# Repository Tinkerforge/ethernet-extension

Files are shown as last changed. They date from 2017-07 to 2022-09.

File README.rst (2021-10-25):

Ethernet Extension
==================

This repository contains the hardware design files.
The software is included in the Master Brick software
and can be found at https://github.com/Tinkerforge/master-brick

Repository Content
------------------

hardware/:
 * Contains KiCad project files and additionally schematics as PDF

datasheets/:
 * Contains datasheets for sensors and complex ICs that are used

Hardware
--------

The hardware is designed with the open source EDA Suite KiCad
(http://www.kicad.org). Before you are able to open the files,
you have to install the Tinkerforge kicad-libraries
(https://github.com/Tinkerforge/kicad-libraries). You can either clone
them directly in hardware/ or clone them in a separate folder and
symlink them into hardware/
(ln -s kicad_path/kicad-libraries project_path/hardware). After that you
can open the .pro file in hardware/ with KiCad and from there view and
modify the schematics and the PCB layout.

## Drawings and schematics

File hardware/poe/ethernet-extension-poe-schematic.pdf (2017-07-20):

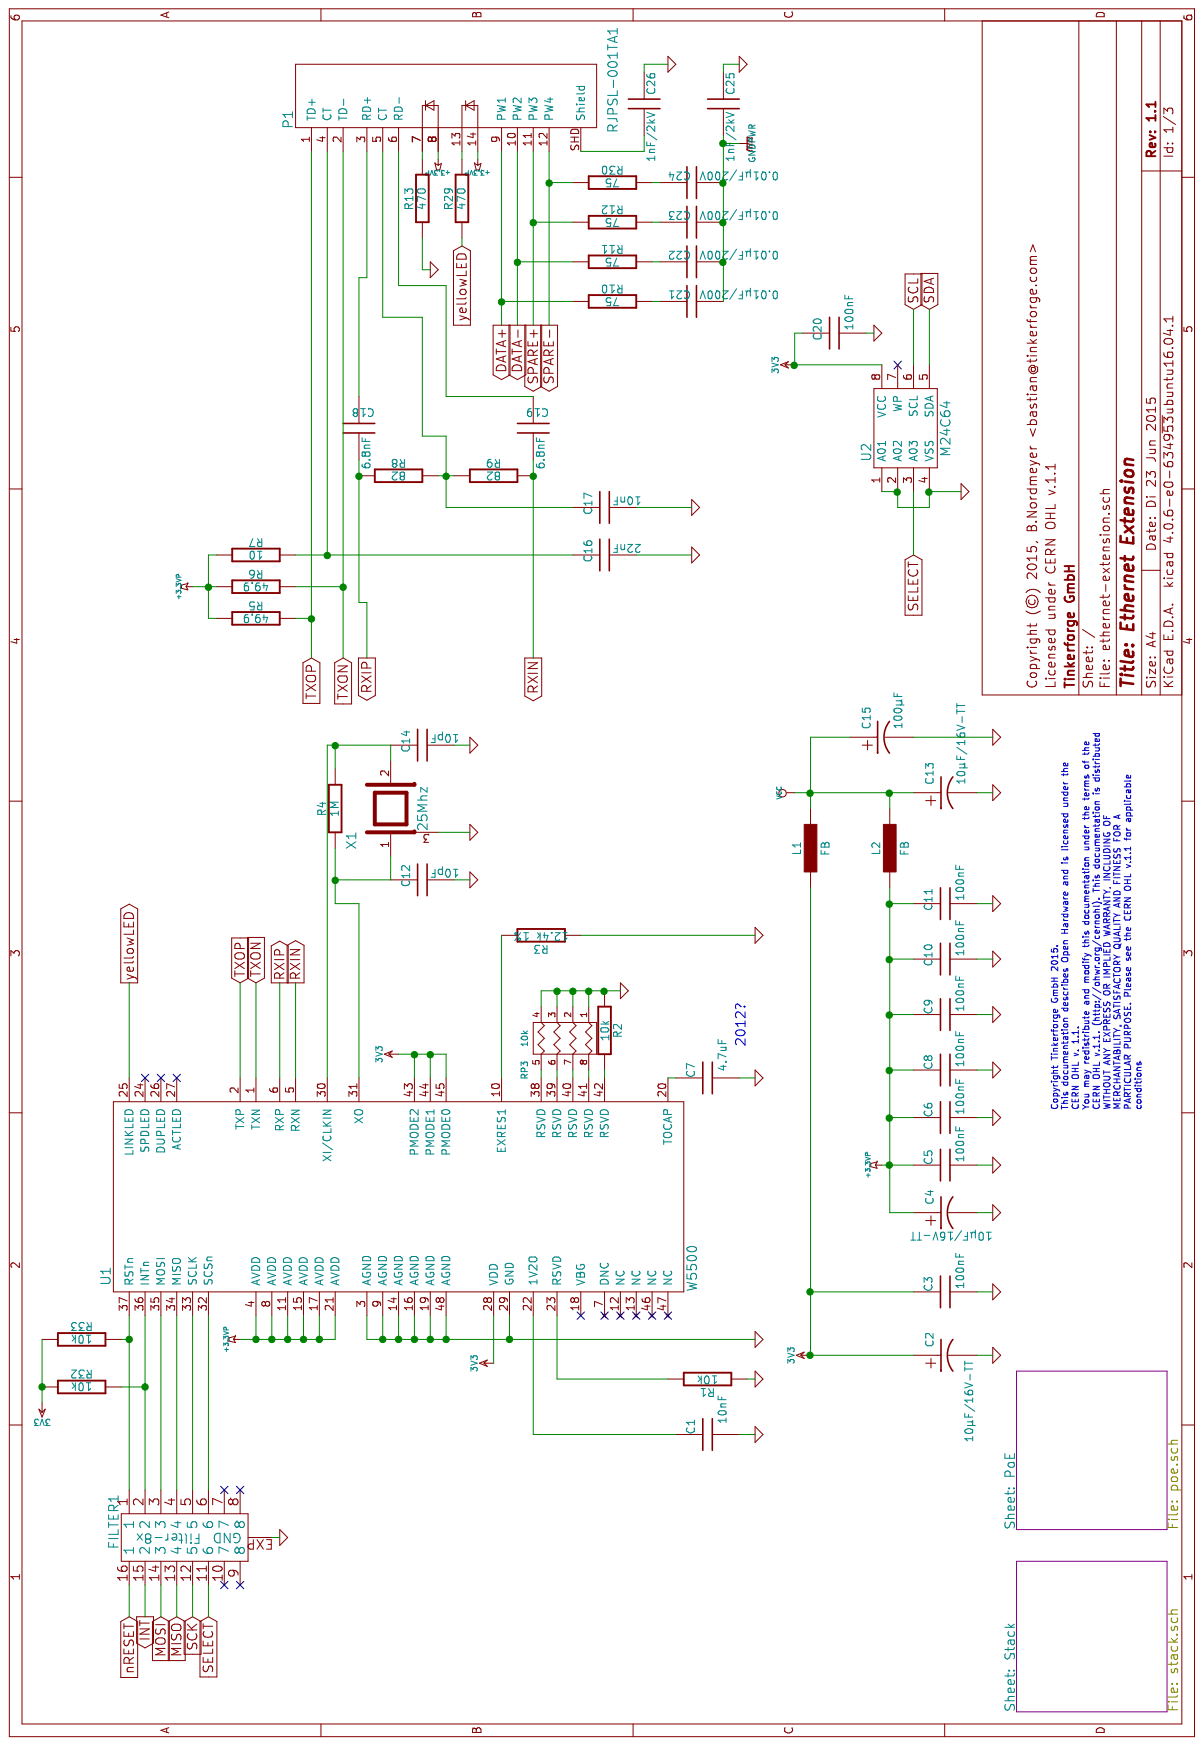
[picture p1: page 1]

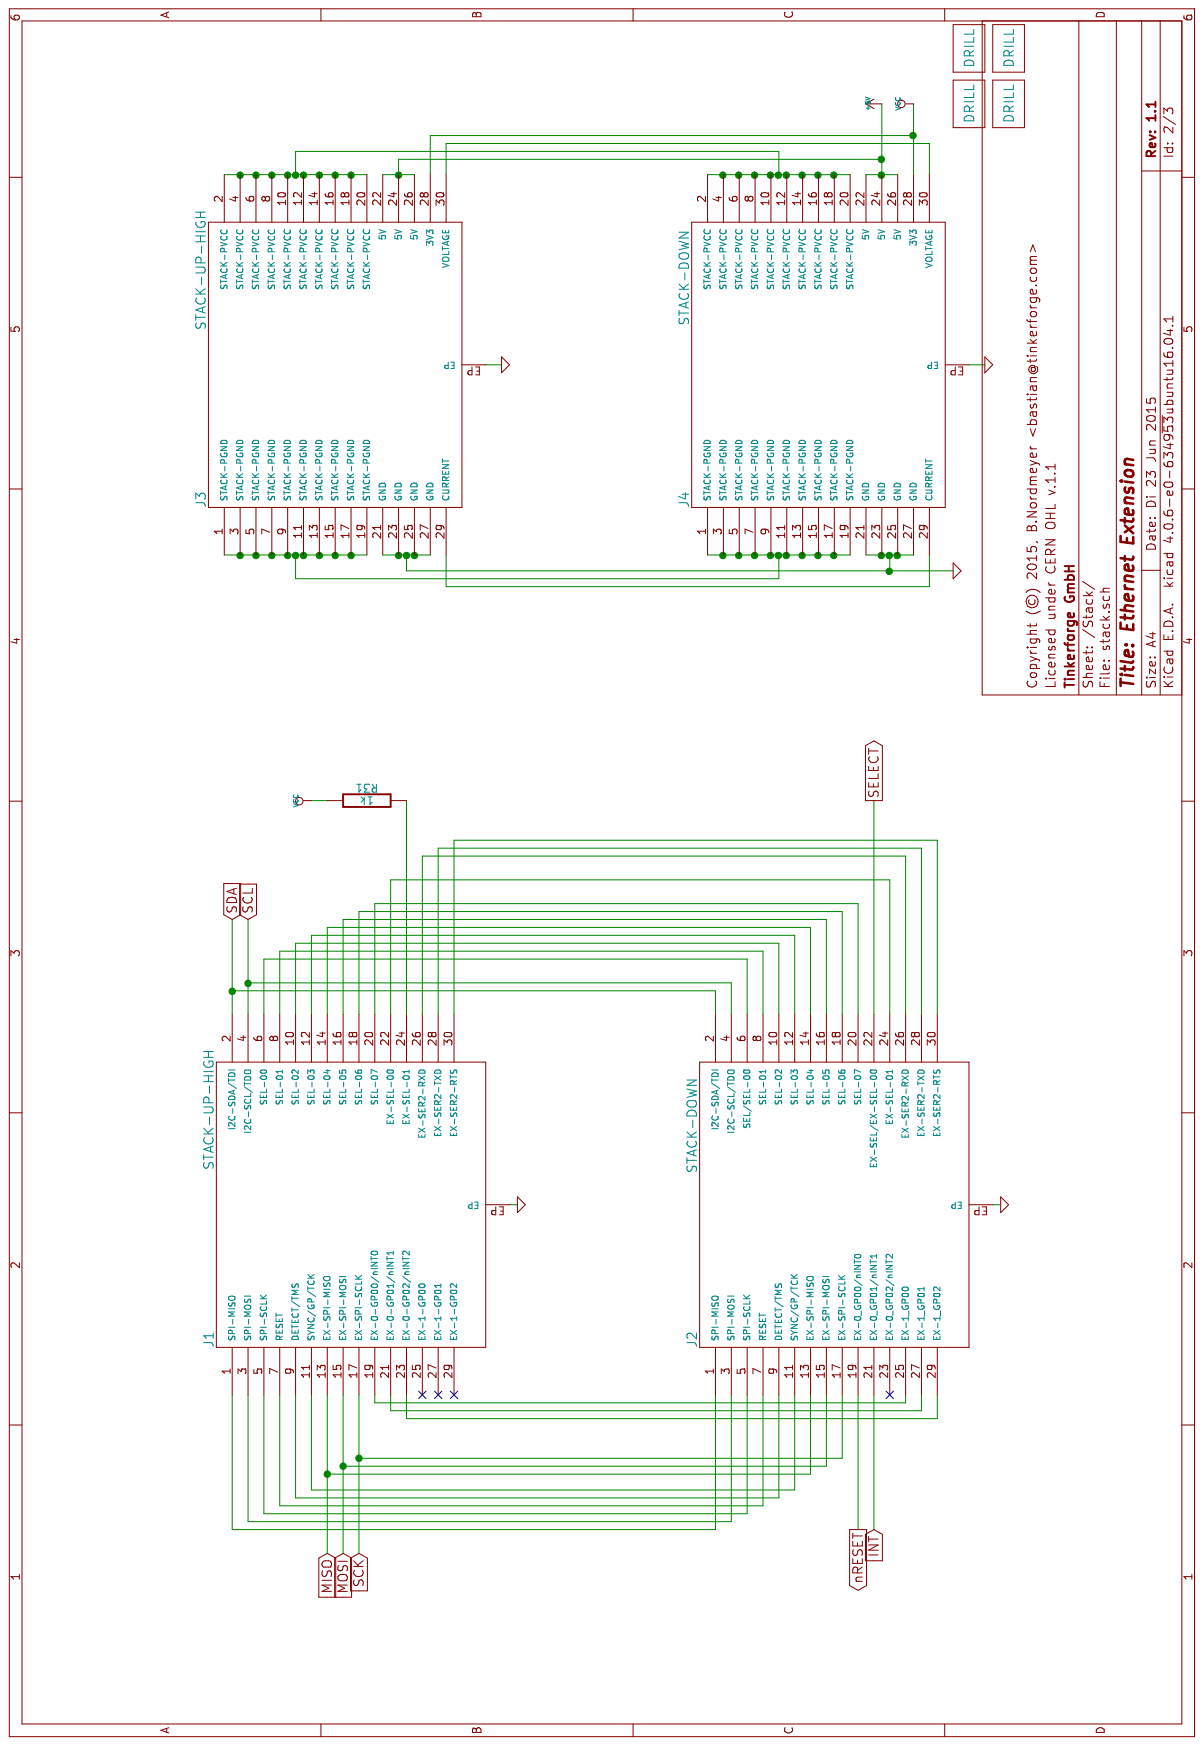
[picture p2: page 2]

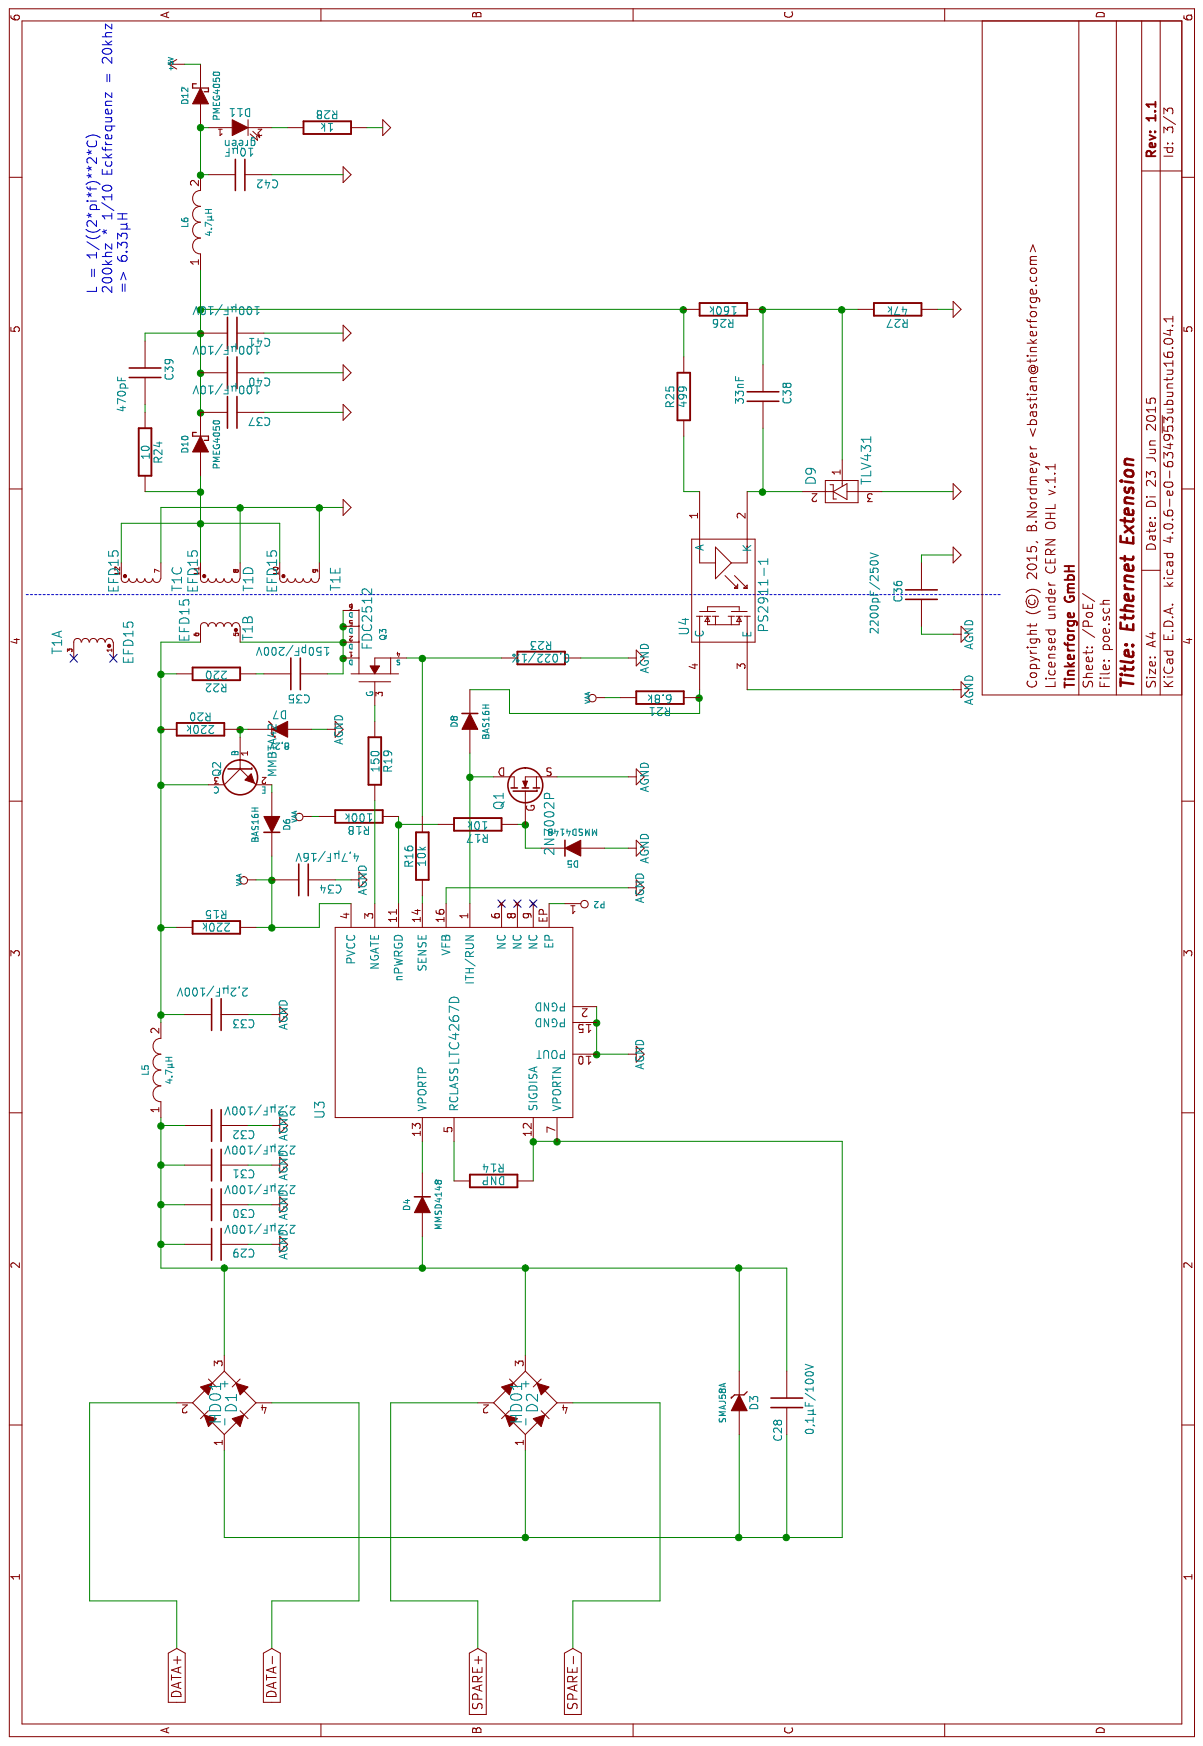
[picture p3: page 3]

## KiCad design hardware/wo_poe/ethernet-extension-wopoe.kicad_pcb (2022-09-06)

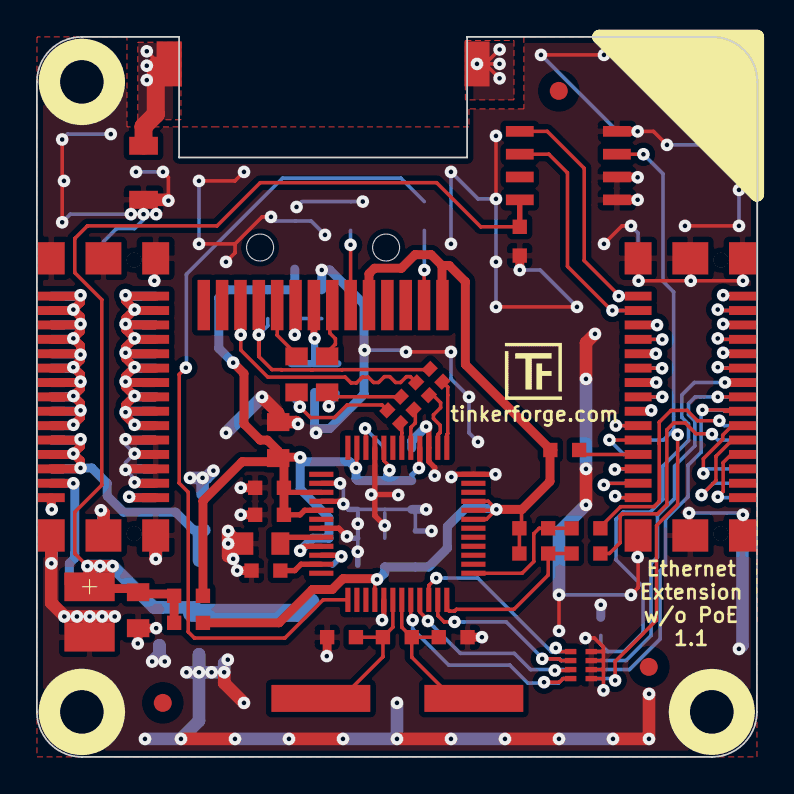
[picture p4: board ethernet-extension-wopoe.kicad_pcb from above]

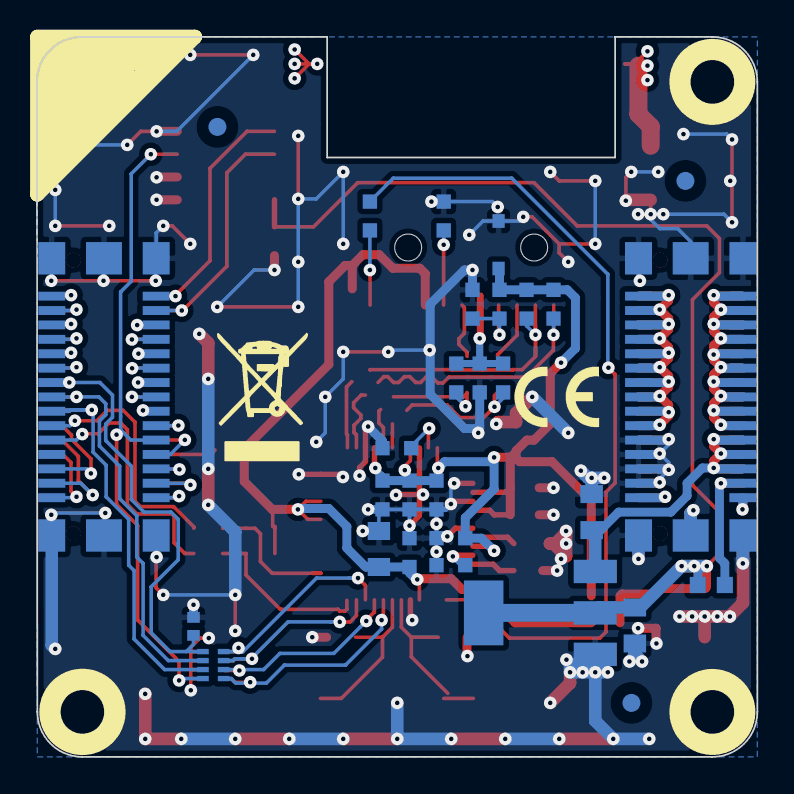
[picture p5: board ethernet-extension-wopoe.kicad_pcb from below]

Board: 2 copper layers, 40.0 x 40.0 mm, 70 parts (33 on the bottom side), 68 nets.

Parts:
C1, C4, C13: 10µF/16V-TT; 0805P
C2, C17: 10nF; C0603
C3, C5, C6, C7, C8, C10, C11, C20: 100nF; C0603
C9, C102, C103: 4.7uF; C0805
C12, C15: 10pF; C0603
C14: 100µF; 3528-21
C16: 22nF; C0603
C18, C19: 6.8nF; C0805
C21: 1nF/2kV; C1206
C101: 10pF; C0402F
D101: ‎PESD3V3L1BA; SOD-323
Fiducial_Mark: VAL**; Fiducial_Mark
Fiducial_Mark#2, Fiducial_Mark#3, Fiducial_Mark#4, Fiducial_Mark#5, Fiducial_Mark#6: VAL**; Fiducial_Mark
J1, J3: STACK-UP-HIGH; BTB08-ACS-TOP
J2, J4: STACK-DOWN; BTB08-ACS-BTM
L1, L2: FB; C0603
L101: TBD; R0603F
P1: RJPSL-001TA1
R1, R3: 10k; R0603
R2, R106: DNP; R0603
R5: 12.4k 1%; R0603
R6: 1M; R0603
R7, R8, R10, R11: 49.9; R0603
R9: 10; R0603
R12, R13: 470; R0603
R14, R105: 1k; R0603
R101, R102, R103, R104: 33; R0402F
RP102: 82; 4X0402
RP103: DNP; 4X0402
U1: W5500; LQFP48
U2: M24C64; SOIC8
U3, U4, U5, U6: DRILL; DRILL_NP
U101: AZ1117-3V3; SOT-223
VAL: WEEE_7mm
VAL#2: CE_5mm
X1: 25Mhz; HC49_US

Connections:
3V3: C1.1, C3.2, L1.1, P1.8, P1.14, R1.2, R2.2, R14.1, U1.28, U1.43, U1.44, U1.45
+3.3VP: C4.1, C5.2, C6.2, C7.2, C8.2, C10.2, C11.2, D101.1, L2.1, R7.1, R8.1, R9.1, U1.4, U1.8, U1.11, U1.15, U1.17, U1.21
GND: C1.2, C2.1, C3.1, C4.2, C5.1, C6.1, C7.1, C8.1, C9.1, C10.1, C11.1, C12.1, C13.2, C14.2, C15.1, C16.1, C17.1, C20.1, C21.2, C101.1, C102.1, C103.1, D101.2, J1.EP, J2.EP, J3.21, J3.23, J3.25, J3.27, J3.EP, J4.21, J4.23, J4.25, J4.27, J4.EP, R3.1, R5.1, R12.1, RP103.1, RP103.2, RP103.3, RP103.4, U1.3, U1.9, U1.14, U1.16, U1.19, U1.29, U1.48, U2.1, U2.2, U2.4, U101.1
INT: J2.21, R106.1
MISO: C101.2, J1.13, J2.13, RP102.1
MOSI: J1.15, J2.15, RP102.2
unnamed: C2.2, U1.22
unnamed: C9.2, U1.20
unnamed: C12.2, R6.1, U1.31, X1.1
unnamed: C15.2, R6.2, U1.30, X1.2
unnamed: C16.2, P1.4, R9.2
unnamed: C17.2, P1.5, R10.2, R11.1
unnamed: C18.1, R10.1, R103.1
unnamed: C18.2, P1.3
unnamed: C19.1, R11.2, R104.1
unnamed: C19.2, P1.6
unnamed: J1.1, J2.1
unnamed: J1.3, J2.3
unnamed: J1.5, J2.5
unnamed: J1.6, J2.6
unnamed: J1.7, J2.7
unnamed: J1.8, J2.8
unnamed: J1.9, J2.9
unnamed: J1.10, J2.10
unnamed: J1.11, J2.11
unnamed: J1.12, J2.12
unnamed: J1.14, J2.14
unnamed: J1.16, J2.16
unnamed: J1.18, J2.18
unnamed: J1.19, J2.25
unnamed: J1.20, J2.20
unnamed: J1.21, J2.27
unnamed: J1.22, J2.24
unnamed: J1.23, J2.29
unnamed: J1.24, R14.2
unnamed: J1.26, J2.26
unnamed: J1.28, J2.28
unnamed: J1.30, J2.30
unnamed: J3.1, J3.3, J3.5, J3.7, J3.9, J3.11, J3.13, J3.15, J3.17, J3.19, J4.1, J4.3, J4.5, J4.7, J4.9, J4.11, J4.13, J4.15, J4.17, J4.19
unnamed: J3.2, J3.4, J3.6, J3.8, J3.10, J3.12, J3.14, J3.16, J3.18, J3.20, J4.2, J4.4, J4.6, J4.8, J4.10, J4.12, J4.14, J4.16, J4.18, J4.20
unnamed: J3.29, J4.29
unnamed: J3.30, J4.30
unnamed: P1.1, R7.2, R101.1
unnamed: P1.2, R8.2, R102.1
unnamed: P1.7, R12.2
unnamed: P1.13, R13.2
unnamed: R1.1, R105.2, U1.37
unnamed: R3.2, U1.23
unnamed: R5.2, U1.10
unnamed: R2.1, R106.2, U1.36
unnamed: RP102.5, RP103.8, U1.32
unnamed: RP102.6, RP103.7, U1.33
unnamed: RP102.7, RP103.6, U1.35
unnamed: RP102.8, RP103.5, U1.34
RXIN: R104.2, U1.5
RXIP: R103.2, U1.6
S3V3: J3.28, J4.28, L101.1
S5V: C102.2, J3.22, J3.24, J3.26, J4.22, J4.24, J4.26, U101.3
SCK: J1.17, J2.17, RP102.3
SCL: J1.4, J2.4, U2.6
SDA: J1.2, J2.2, U2.5
SELECT: J2.22, RP102.4, U2.3
SHD: C21.1, P1.SHD
TXON: R102.2, U1.1
TXOP: R101.2, U1.2
VCC: C13.1, C14.1, C20.2, C103.2, L1.2, L2.2, L101.2, U2.8, U101.2
nRESET: J2.19, R105.1
yellowLED: R13.1, U1.25

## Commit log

2013-05-23 add kicad design files and schematic for ethernet extension
    [ethernet-extension.brd, ethernet-extension.sch, poe.sch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]
2015-06-23 add hardware files for ethernet extension wo poe
    [ethernet-extension.kicad_pcb, ethernet-extension.sch]
2015-06-23 add hardware files for new ethernet extension with W5500 and PoE
    [ethernet-extension.kicad_pcb, ethernet-extension.sch, poe.sch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]
2015-06-23 add missing file
    [stack.sch]
2015-06-23 remove tinkerforge.com text on bottom
    [ethernet-extension.kicad_pcb]
2015-09-28 adapt mosfet series gate resistor
    [ethernet-extension.brd, ethernet-extension.sch, poe.sch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]
2016-04-26 fix schematic
2017-04-20 fix some value texts
    [ethernet-extension.kicad_pcb]
2017-07-20 fix schematic symbols
    [ethernet-extension.kicad_pcb, ethernet-extension.sch, poe.sch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]
2017-07-20 make color schematic
2017-07-20 add schematic for non poe version
2017-07-20 fix schematic naming
2017-07-20 remove files of old version
    [ethernet-extension.sch, poe.sch, stack.sch]
2017-08-03 Add 3d information (final)
    [ethernet-extension.kicad_pcb, ethernet-extension.sch, stack.sch]
2017-08-03 Add 3d model (*.step & *.FCStd)
    [ethernet-extension.kicad_pcb]
2017-08-03 Add 3d information (tbc)
    [ethernet-extension.kicad_pcb, ethernet-extension.sch, poe.sch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]
2018-05-11 PoE: rename files
    [ethernet-extension-poe.kicad_pcb, ethernet-extension-poe.sch]
2018-05-11 w/o PoE: Rename files
    [ethernet-extension-wopoe.kicad_pcb, ethernet-extension-wopoe.sch]
2020-05-25 fix library settings
    [ethernet-extension-poe.sch, poe.sch, stack.sch]
2021-10-25 Update KiCad link
    https://www.kicad.org/blog/2021/10/Avoid-links-to-former-kicad-domain/
2022-09-06 add data of ethernet extension 1.1
    move to kicad 6
    [ethernet-extension-wopoe.kicad_pcb, ethernet-extension-wopoe.kicad_sch, ethernet-extension-wopoe.sch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]

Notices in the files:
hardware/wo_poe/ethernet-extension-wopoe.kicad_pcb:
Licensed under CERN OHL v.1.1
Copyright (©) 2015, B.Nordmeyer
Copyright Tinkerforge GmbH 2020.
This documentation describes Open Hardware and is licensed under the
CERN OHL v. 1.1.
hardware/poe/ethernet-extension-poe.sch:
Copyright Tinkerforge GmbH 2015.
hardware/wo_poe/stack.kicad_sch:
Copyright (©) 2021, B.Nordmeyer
